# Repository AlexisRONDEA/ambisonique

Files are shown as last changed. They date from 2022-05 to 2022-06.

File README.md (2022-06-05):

#	  Projet : Ambisonique
  
Collaborateurs : RONDEAU Alexis, SOULE Zeïck, BODET Amaury, VAN DE MOOSDIJK Martina, MILLASSEAU Adrien, LATHUILLERE Colin

###	I / Introduction
	
Ce projet, initialement conçu par des troisièmes années, permet de connecter huit enceintes pour délivrer un son provenant de différentes directions.
Nos objectifs concernent l’encombrement et la qualité sonore de l’amplificateur audio. En effet, les enceintes sont pour l’instant alimentées par des alimentations de laboratoire, ce qui est peu pratique et prend de la place. De plus, le signal audio est transmis par un seul fil. Cette liaison asymétrique est la source de parasite sur le signal et donne lieu à une mauvaise qualité sonore. 
On se propose donc de remplacer la transmission du signal par une liaison symétrique différentielle, pour supprimer le plus de parasites possible. On change l’amplificateur actuel par un amplificateur de classe D pour améliorer la qualité sonore du signal en sortie. Enfin, on fait passer l’alimentation des enceintes par le câble transmettant le signal audio, pour alimenter les enceintes avec le réseau.
Pour cela on sépare ce projet en quatre modules et en deux PCB. Les deux premiers appartiendront au premier et le séparateur avec l’ampli audio seront sur le deuxième PCB.

Objectifs : 
- Créer un module modifiant le courant d'entrée du réseau 230V AC en 24V DC
- Créer un module qui additionne la partie continue de 24V au signal
- Créer un module qui sépare le signal et la puissance pour alimenter les enceintes
- Créer l’amplificateur de classe D
 
Le [cahier des charges](https://github.com/AlexisRONDEA/ambisonique/blob/main/livrables/Cahier%20des%20Charges%20-%20Ambisonique%20%5B2%5D.pdf), le [diagramme d’architecture](https://github.com/AlexisRONDEA/ambisonique/blob/main/livrables/Diagramme%20Architecture%20-%20Ambisonique%20%5B2%5D.pdf), la [présentation PDF](https://github.com/AlexisRONDEA/ambisonique/blob/main/livrables/Diagramme%20Architecture%20-%20Ambisonique%20%5B2%5D.pdf) du projet ainsi que les [commandes des composants](https://github.com/AlexisRONDEA/ambisonique/tree/main/livrables) se trouvent dans le dossier « [livrables](https://github.com/AlexisRONDEA/ambisonique/tree/main/livrables) ».

###	II / Alimentation du circuit

Pour ce module on utilise les composants suivants :
-	Un connecteur MPT 0.5/2-2.54
-	Un transformateur PCB, 230V, 2 * 24V
-	Un pont redresseur monophasé
-	Un contrôleur DC/DC, synchrone, Buck, output 24V

Le transformateur permet de modifier la tension d’entrée du réseau de 230V alternatif en 24V alternatif. Le courant est ensuite envoyé dans le pont de diode redresseur qui renvoie une tension de 33V continu en sortie. Enfin, le contrôleur Buck abaisse la tension à 24V continu pour l’envoyer dans le module additionneur.

Dans un premier temps, pour créer ce module on voulait utiliser un montage avec un régulateur de tension. Cependant, ce circuit était assez vieux et donc pas assez performant par rapport à d’autres montages envisageables. Les pertes étaient trop importantes et c’est pour cela que nous avons décidé d’opter pour ce circuit actuel. 
De plus, notre circuit actuel devait utiliser les deux branches de sortie du transformateur qui fournit du 2x24V, car une fois 24V n’aurait pas était suffisant. Cependant la tension de sortie correspond à un courant alternatif, qui est donc redresser par le pont de diode ensuite à 33V continu. C’est pourquoi on n’utilise qu’une seule branche de sortie du transformateur.  

 Ce module fait partie du premier PCB, les fichiers utiles au PCB sont donc [ambisoniqueAlim.sch](https://github.com/AlexisRONDEA/ambisonique/blob/main/PCB/SchematicAlim.png) et [ambisoniqueAlim.brd](https://github.com/AlexisRONDEA/ambisonique/blob/main/PCB/BoardAlim.png). Les empreintes du contrôleur Buck et du transformateur ont été créé pour Eagle tandis que l’empreinte du pont redresseur a été téléchargée sur internet. 

###	III / Additionneur

Pour ce module, on utilise les composants suivants : 

-	Deux transistors de puissance NPN TIP31A 
-	Deux connecteurs Jack 

On réalise un montage à collecteur commun en utilisant le TIP31A. Il permet d'obtenir en sortie, au niveau de l'émetteur et dans le même fil, le signal audio ainsi que les 24 V DC obtenus dans le module précédent. On assure la transmission par un seul câble XLR. On souhaite également avoir un courant de 1.5 A en sortie du transistor, d'où le choix d'un transistor de puissance pour réaliser ce montage. Enfin, on réalise ce montage deux fois, avec un signal audio positif puis négatif afin de pouvoir les soustraire et travailler en différentiel. L'objectif du différentiel est d'éviter les perturbations électromagnétiques, qui se répercutent sur les deux signaux. En les soustrayant, on efface alors les parasites. On souhaite également éviter d'impacter la valeur continue, en choisissant judicieusement la valeur des résistances. 

Nous avons pensé à réaliser ce module en utilisant un schéma additionneur avec un amplificateur opérationnel, néanmoins cela aurait été compliqué car il nous fallait avoir un courant conséquent en sortie, ce qui n'est pas possible avec un AOP. 

Ce module fait partie du premier PCB, les fichiers utiles au PCB sont donc [ambisoniqueAlim.sch](https://github.com/AlexisRONDEA/ambisonique/blob/main/PCB/SchematicAlim.png) et [ambisoniqueAlim.brd](https://github.com/AlexisRONDEA/ambisonique/blob/main/PCB/BoardAlim.png).

 ###	IV / Séparateur 
 
Pour ce module on utilise les composants suivants :
-	Deux contrôleurs DC/DC, synchrone, Buck, output 12V

Pour ce module, on utilise des condensateurs. On utilise leur caractéristique de filtre pour séparer la composante continue et le signal. On souhaite séparer la composante continue afin de l'utiliser en tant qu'alimentation pour les enceintes, et d'utiliser la composante alternative pour l'amplifier dans le module suivant. Les deux câbles de puissance rentrent alors dans les contrôleurs Buck qui renvoient une tension de 12V. On fait se rejoindre les deux câbles, puis on les sépare pour alimenter le microprocesseur et les MOSFET. En effet, les MOSFET sont directement alimentés en 12V, tandis que la tension d’entrée du microprocesseur passe par un régulateur avant d’alimenter le microprocesseur en 3,3V. 

Pour ce module, on a dû recommander les contrôleurs Buck. En effet, ceux commandés ne pouvait que donner du 5V en sortie contrairement aux 12V voulus.

Ce module fait partie du second PCB, les fichiers utiles au PCB sont donc [ambisoniqueAmpli.sch](https://github.com/AlexisRONDEA/ambisonique/blob/main/PCB/SchematicAmpli.png) et [ambisoniqueAmpli.brd](https://github.com/AlexisRONDEA/ambisonique/blob/main/PCB/BoardAmpli.png).

###	V / Amplificateur audio

Pour ce module on utilise les composants suivants :
-	Un microcontrôleur STM32L412KBT6
-	Un MOSFET de puissance, Canal N, 20 V, 3.9 A, 0.025 Ohm
-	Un MOSFET de puissance, Canal P, 20 V, 3.2 A, 0.08 Ohm

L’objectif de cette partie du projet est de remplacer l’amplificateur audio déjà existant en le substituant par un microprocesseur. Ce dernier permet de créer une PWM qui rentre ensuite dans un amplificateur de classe D composé des deux MOSFET de puissance. Pour ce faire, on alimente le microprocesseur avec du 3,3V venant du module séparateur et les MOSFET en 12V. Le microprocesseur récupère le signal différentiel en entrée et le traite, pour retourner un signal simple avec le moins de parasites possible. Ensuite, le signal est comparé à un signal triangle, modélisé par un compteur TIMER sur le microprocesseur, pour générer la PWM. 

Nous voulions d’abord utiliser d’autres circuits, avec d’autres types d’amplificateur. Cependant, cet amplificateur de classe D est le plus performant. 
De plus, la programmation du microprocesseur n’est pas terminée.

Ce module fait partie du second PCB, les fichiers utiles au PCB sont donc [ambisoniqueAmpli.sch](https://github.com/AlexisRONDEA/ambisonique/blob/main/PCB/SchematicAmpli.png) et [ambisoniqueAmpli.brd](https://github.com/AlexisRONDEA/ambisonique/blob/main/PCB/BoardAmpli.png). Les empreintes des MOSFET viennent d’internet, et celle du microprocesseur nous a été fournie en amont.

###	VI / Conclusion

Pour finir, voici les problèmes généraux que l'on a rencontrés ainsi que le résultat des tests effectués. Tout d'abord, nous n'avons pas testé les contrôleurs Buck séparément du reste du circuit. En effet, nous n'avons pas fait de PCB unitaire avant de passer au PCB complet. De plus, nous n'avons pas placé de points de test pour vérifier le bon fonctionnement de notre circuit. Finalement, nous aurions dû vérifier l'isolation nécessaire entre les pistes parcourue par le courant issu du réseau, pour être certain d'éviter le phénomène d'arc électrique. 

Lors des tests des PCB, on a remarqué que les Bucks ne fonctionnaient pas, sûrement à cause d'une mauvaise soudure. Quant à l'autre PCB, il y a échauffement des composants et la tension de sortie est de 15V au lieu de 24V comme attendu. Il faudrait aussi tester le code du microprocesseur, et voir si ce dernier s'allume correctement avec le reste du circuit.

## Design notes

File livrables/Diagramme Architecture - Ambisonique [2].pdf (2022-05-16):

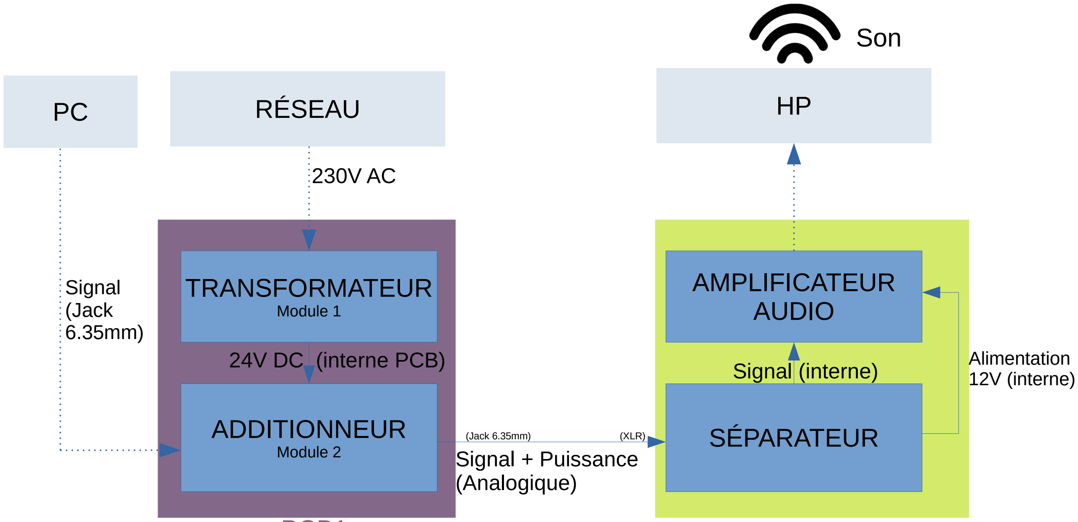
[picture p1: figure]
TRANSFORMATEUR; Module 1; ADDITIONNEUR; Module 2; Signal (Jack 6.35mm); Signal + Puissance (Analogique); (interne PCB); SÉPARATEUR; AMPLIFICATEUR AUDIO; Signal (interne); Alimentation; 12V (interne); RÉSEAU; Son; (Jack 6.35mm); (XLR)

PCB1 | PCB2

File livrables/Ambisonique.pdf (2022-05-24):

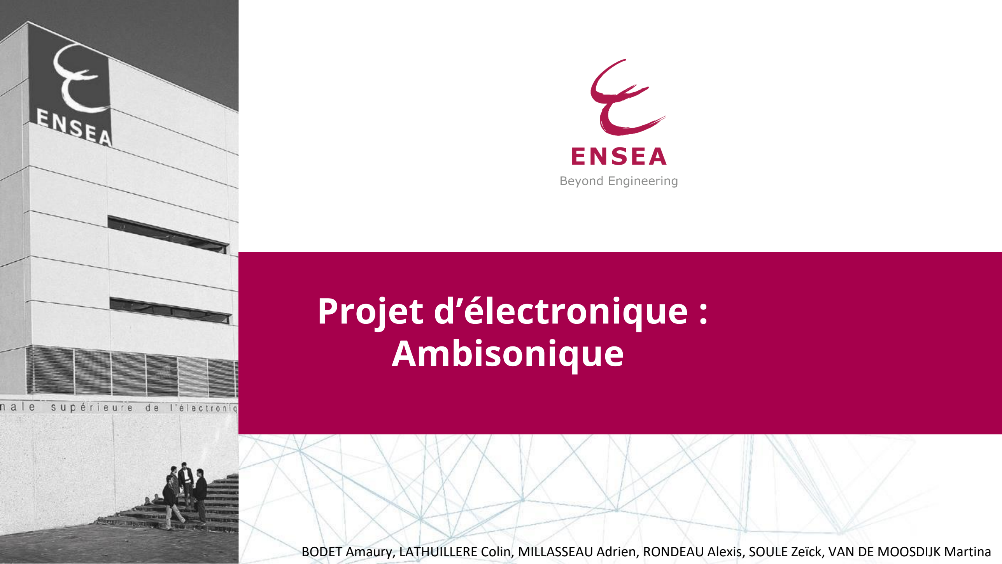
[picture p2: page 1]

## Projet d’électronique : Ambisonique

BODET Amaury, LATHUILLERE Colin, MILLASSEAU Adrien, RONDEAU Alexis, SOULE Zeïck, VAN DE MOOSDIJK Martina

## Sommaire

Mai 2022 – 2 / 21

1

2

4

3

Présentation générale du projet

Module Alimentation 230V AC – 12V DC

Module Ampli audio 15 W sous 8Ω

Module Signal audio symétrique + puissance en câble XLR

5 Conclusion

## Présentation générale du projet

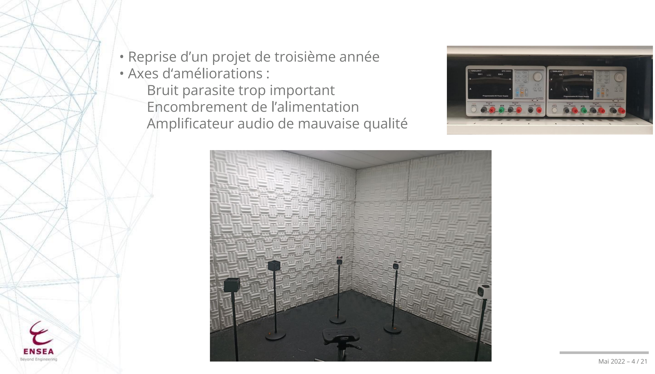
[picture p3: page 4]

- Reprise d’un projet de troisième année
- Axes d‘améliorations :
Bruit parasite trop important Encombrement de l’alimentation Amplificateur audio de mauvaise qualité

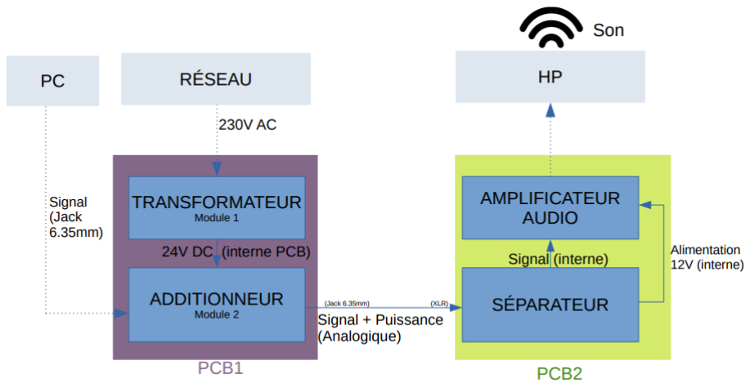
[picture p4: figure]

## Module Alimentation 230V AC – 12V DC

Contraintes:
- Norme IP40D
- Dimensions finales égales à celle d’un rack audio

Objectifs:
- Transformation du courant 230V AC vers 24V DC
- Branchement au secteur

### Introduction

### Schéma du module

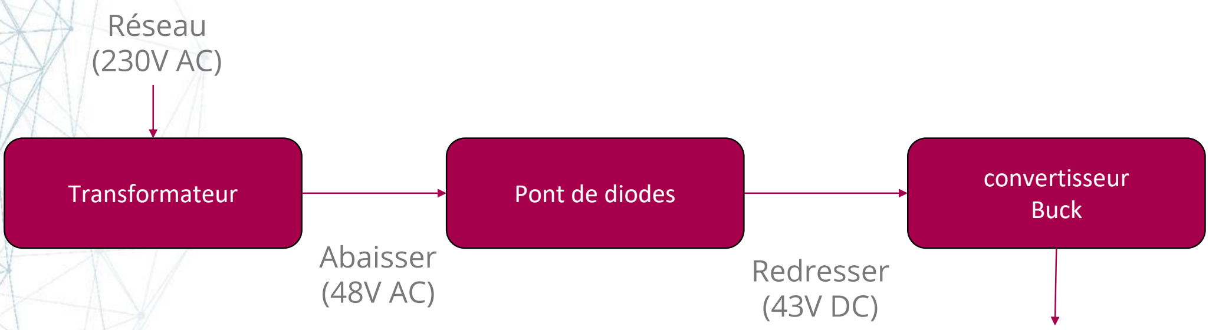
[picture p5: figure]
Transformateur; Pont de diodes; convertisseur; Buck; Réseau (230V AC); Abaisser; Redresser

Additionneur
(24V DC)

### PCB

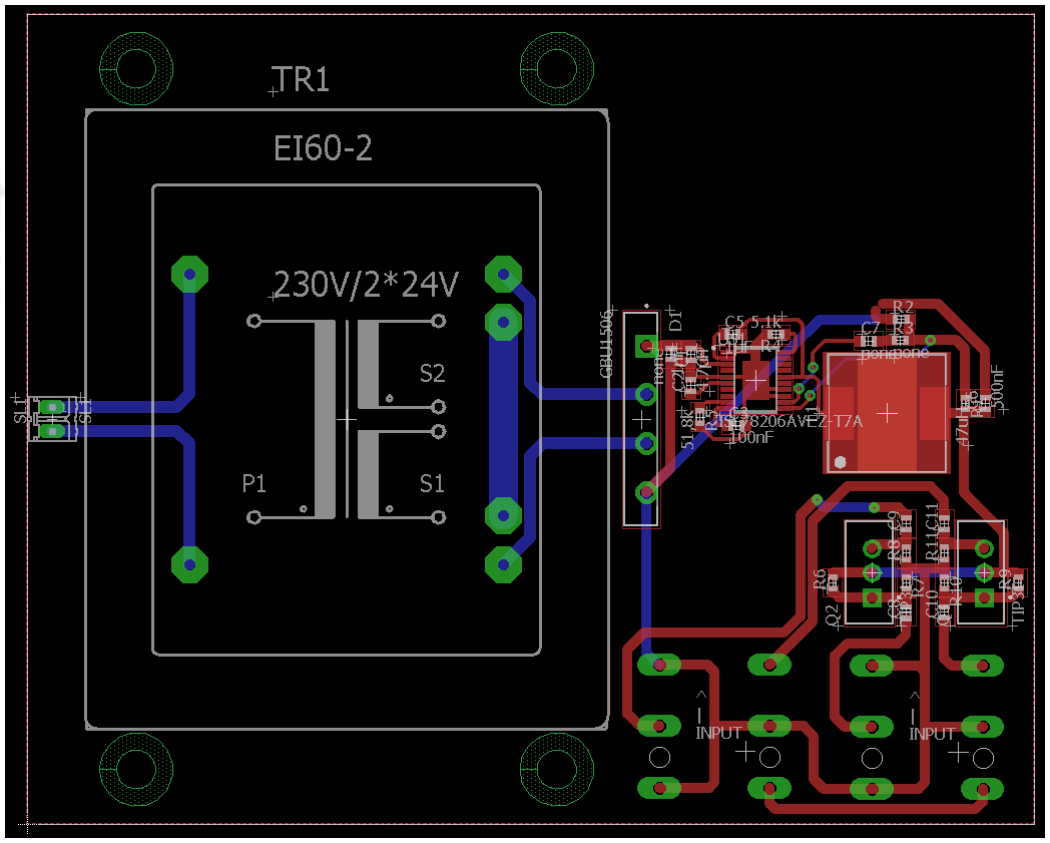
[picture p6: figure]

## Module Signal audio symétrique + puissance en câble XLR

Contraintes:
- Utilisation d’un seul câble de transmission
- Transmission d’un signal différentiel

Objectifs:
- Addition du signal à la puissance
- Transmission du signal sans parasites
- Séparation du signal et du continue

### Introduction

### Schéma du module

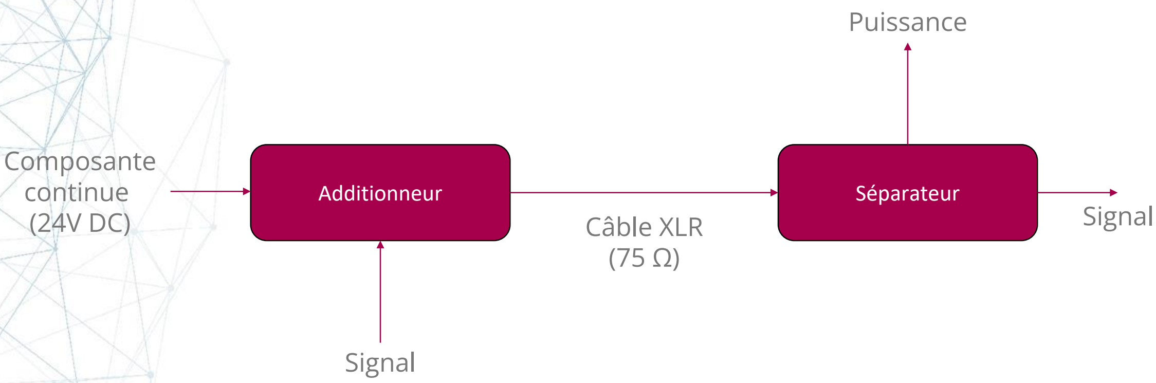
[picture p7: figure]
Additionneur; Séparateur; Composante continue (24V DC); Signal; Puissance; Câble XLR (75 Ω)

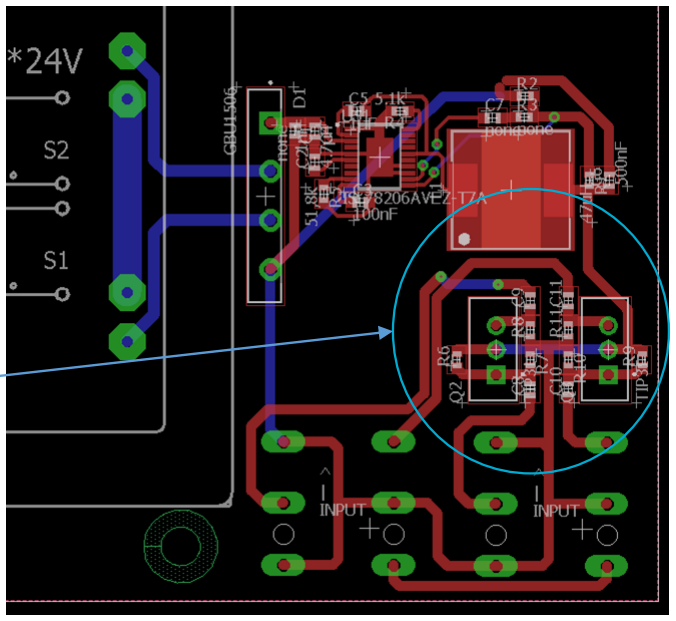
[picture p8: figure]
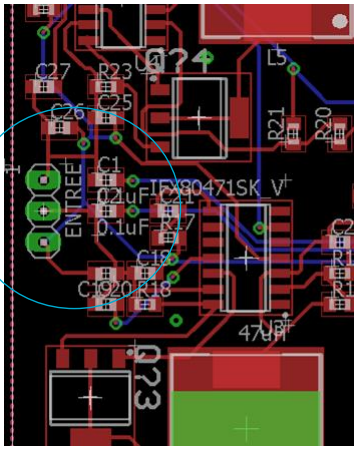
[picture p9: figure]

Additionneur
Séparateur

### PCB

## Module Ampli audio 15 W sous

8Ω

Contraintes:
- Utilisation du microprocesseur
- Amplification du signal de 15W sous 8Ω

Objectifs:
- Amplification du signal
- Transformation du signal différentiel
- Régulation de la puissance d’alimentation

### Introduction

Schéma du | PCB

### module

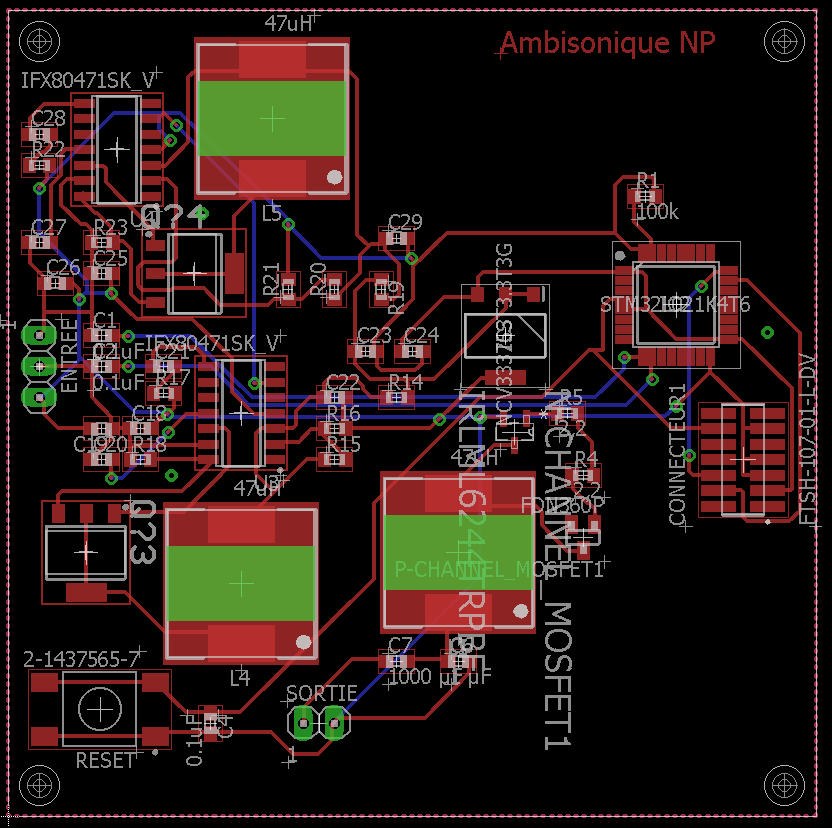
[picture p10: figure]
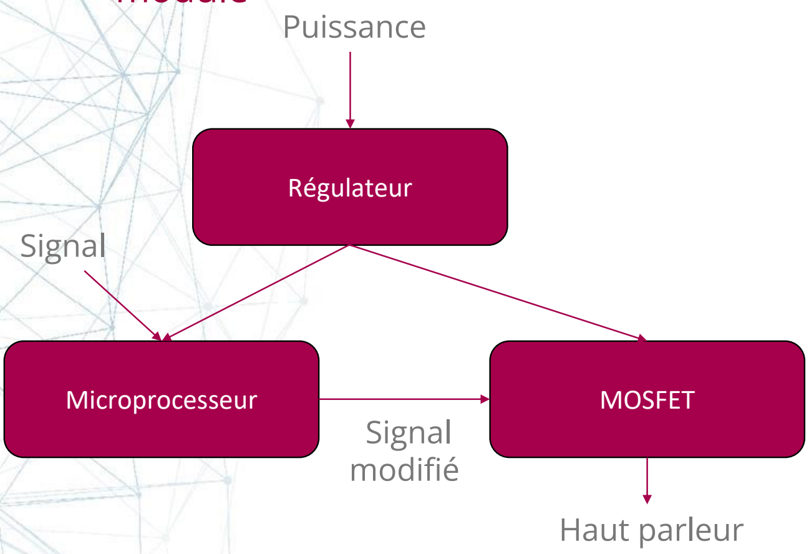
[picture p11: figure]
Régulateur; Microprocesseur; MOSFET; Puissance; Signal; Haut parleur; Signal modifié

### Programmation du microprocesseur

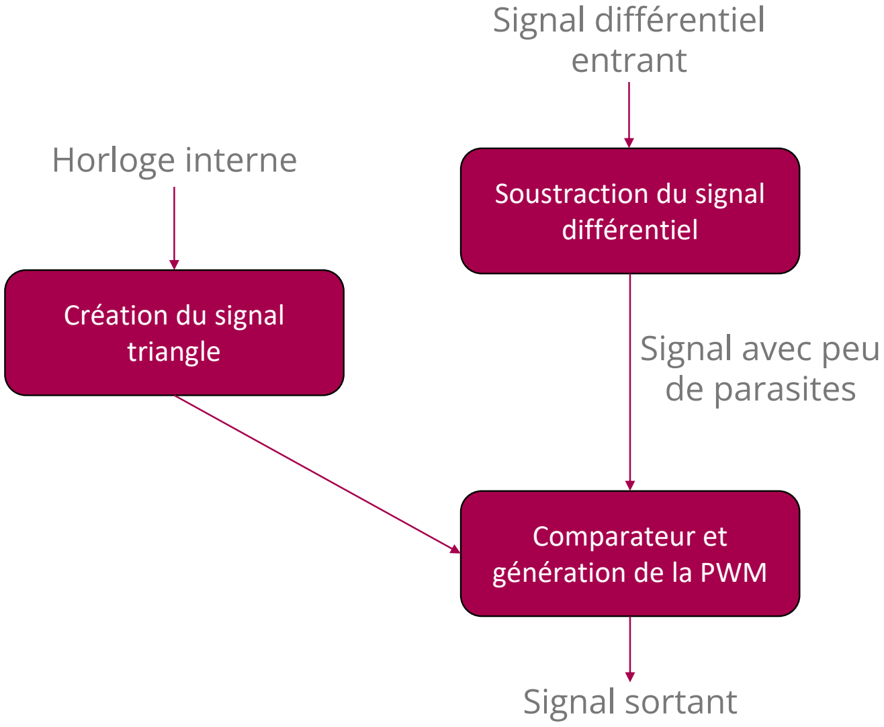
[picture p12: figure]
Création du signal triangle; Soustraction du signal différentiel; Comparateur et génération de la PWM; Signal sortant; Horloge interne; Signal différentiel entrant; Signal avec peu de parasites

## Conclusion

Objectifs à atteindre :
- Finir le PCB
- Terminer le code du microprocesseur
- Tester les modules

### Conclusion

Axes de développement :
- Création d’un boîtier plastique pour le module de transformation du courant
- Multiplication du projet pour les huit enceintes initiales
- Interface homme-machine pour mettre hors tension

### Conclusion

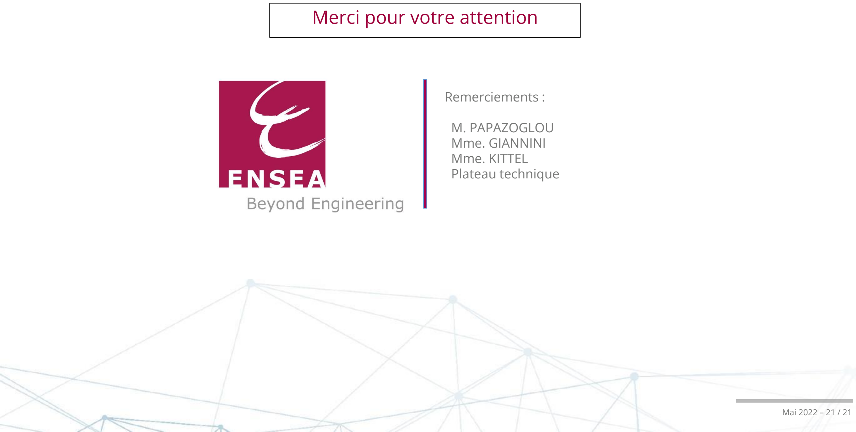
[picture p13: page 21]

Remerciements :

M. PAPAZOGLOU
Mme. GIANNINI
Mme. KITTEL
Plateau technique

Merci pour votre attention

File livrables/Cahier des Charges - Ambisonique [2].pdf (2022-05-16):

Adrien MILLASSEAU - Colin LATHUILLERE - Zeïck SOULE - Alexis RONDEAU - Amaury BODET – Martina VAN DE MOOSDIJK

# CAHIER DES CHARGES

Système ambisonique

OBJECTIF :
Amélioration hardware d’un projet de 3eme année SIA (Système de spatialisation sonore ambisonique).
1) Module 1 : Transformateur
- Transformation du courant
- Entrée : 230V AC (Réseau)
- Sortie : 12V DC
- Norme IP
➢IP 40D
(Protection de la personne contre l’accès aux parties dangereuses avec un fil)
- Réduction de l’encombrement
- Dimensions visées : 42 x 33 x 4.5 cm
- Commun Module 1 et 2
2) Module 2 : Additionneur 12 DC avec signal
- Passage de l’alimentation et du signal dans un seul câble ➢Entrée : Signal (Jack 6.35mm)
➢Sortie : Puissance (1.5A / HP) + Signal (Jack 6.35mm)
- Analogiquement
3) Module 3 : Ampli audio, séparation puissance et signal
- Entrée : 12V + signal (provenant de l’additionneur)
- Séparation puissance/signal analogique
- Echantillonage du signal par Codec
- Filtrage numérique par microprocesseur
- Amplification du signal (ampli 15W pour une charge de 8Ω)

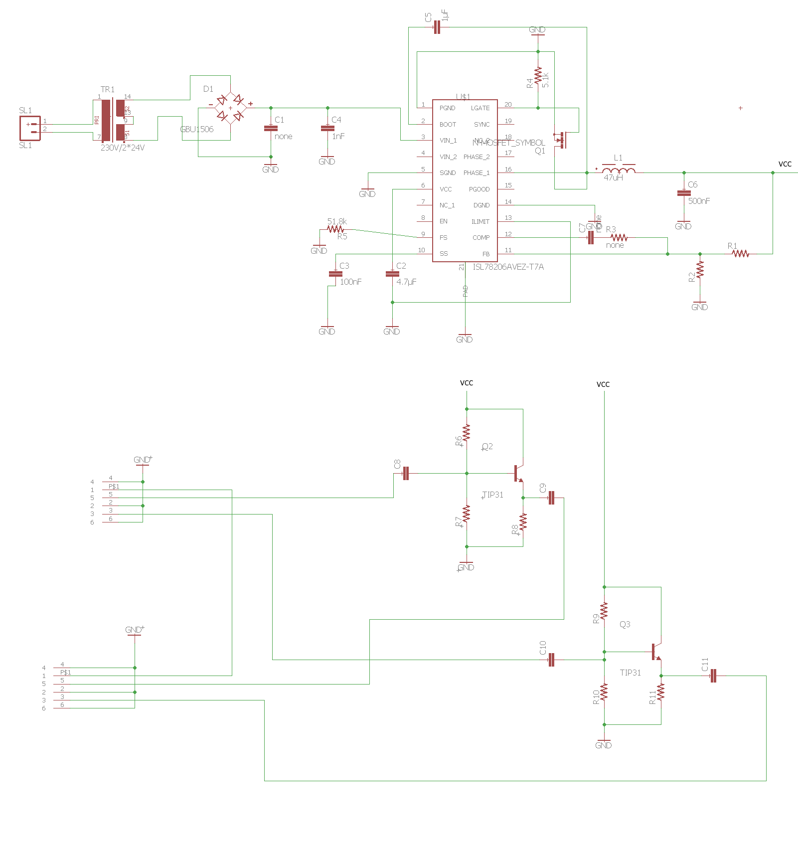
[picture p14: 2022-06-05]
PCB/SchematicAlim.png

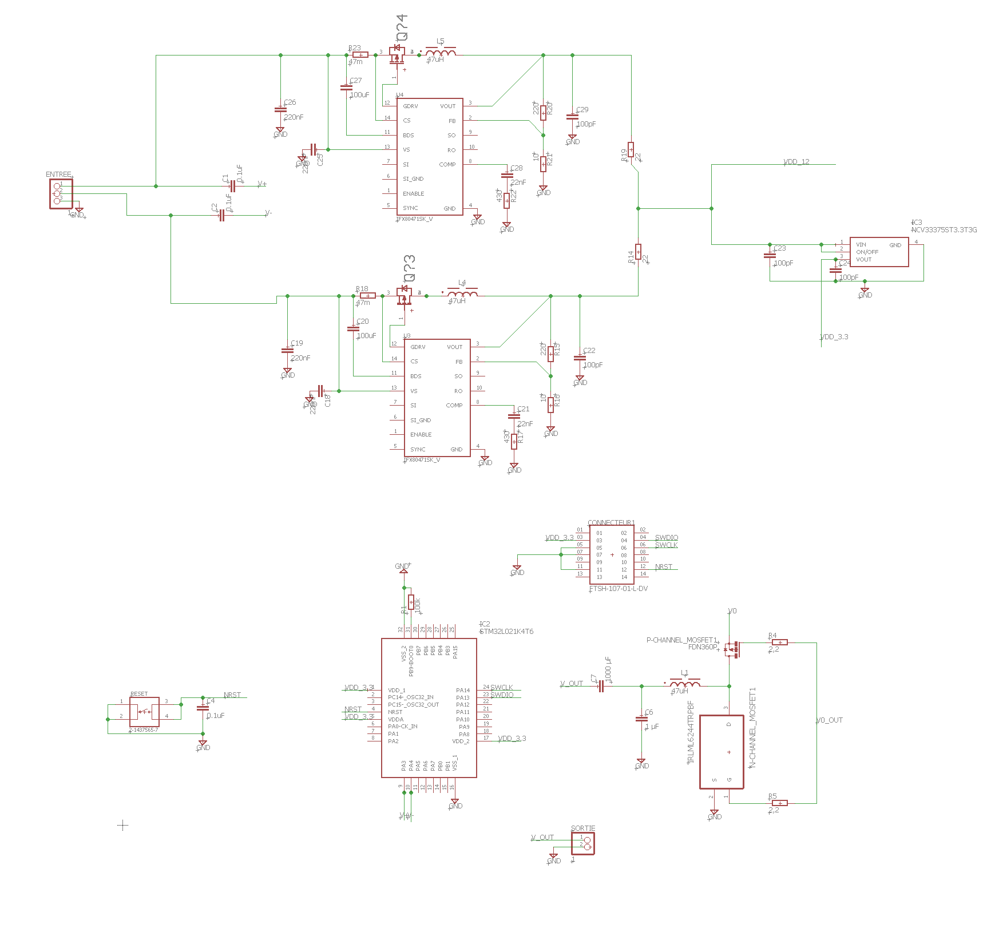
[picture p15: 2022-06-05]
PCB/SchematicAmpli.png

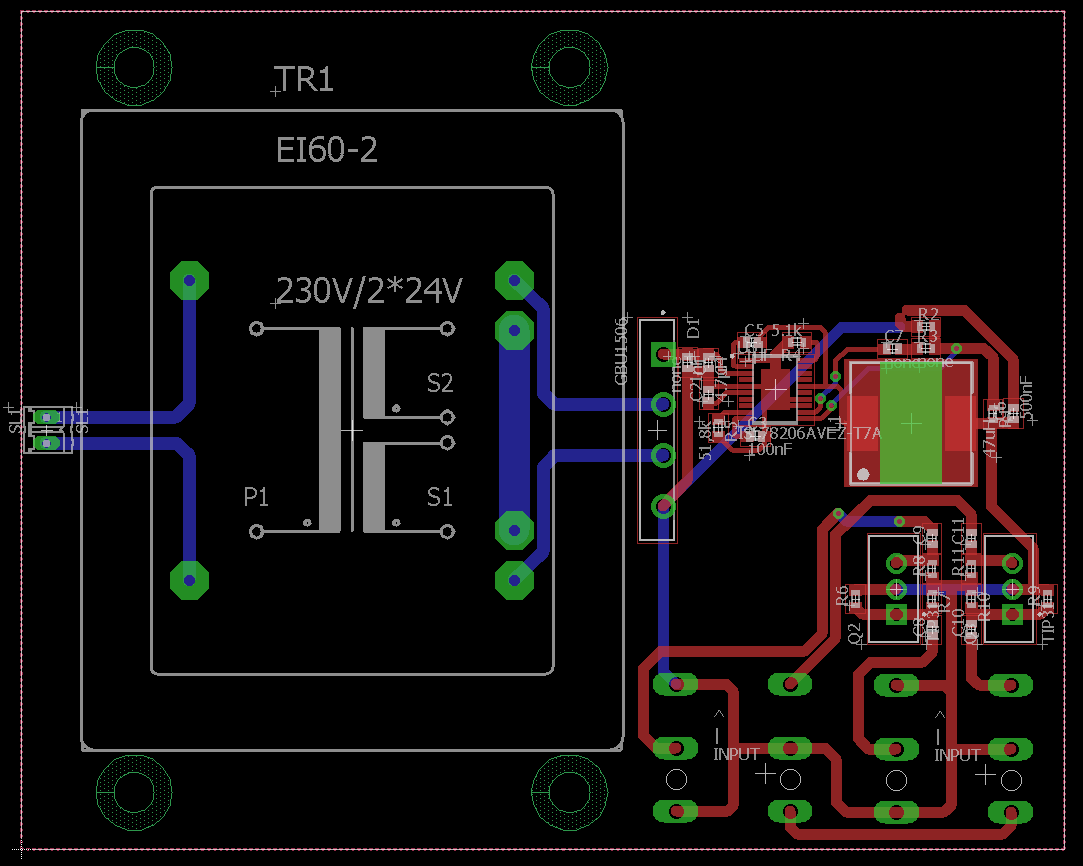
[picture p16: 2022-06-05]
PCB/BoardAlim.png

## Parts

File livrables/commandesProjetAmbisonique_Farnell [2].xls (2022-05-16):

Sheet: 1 commande par mail
Farnell |  |  |  |  | Envoyez un seul fichier par mail!
Pos | I | P | Art | Désignation | Qté commandée | UA | Date Livraison | Prix unitaire | Devise | Q | Grpe | Div
10 | Z |  |  | 2780880 Controleur DC/DC Output 12V | 1 | PC | 17.05.2022 | 2.43 | EUR | PC | TA.01
20 | Z |  |  | 9294333 Transistor TIP31A | 2 | PC | 17.05.2022 | 1.55 | EUR | PC | TA.01
30 | Z |  |  | 2543346 Controleur DC/DC Output 24V | 1 | PC | 17.05.2022 | 6.98 | EUR | PC | TA.01
40 | Z |  |  |  |  | PC |  |  | EUR | PC | TA.01
50 | Z |  |  |  |  | PC |  |  | EUR | PC | TA.01
60 | Z |  |  |  |  | PC |  |  | EUR | PC | TA.01
70 | Z |  |  |  |  | PC |  |  | EUR | PC | TA.01
80 | Z |  |  |  |  | PC |  |  | EUR | PC | TA.01
90 | Z |  |  |  |  | PC |  |  | EUR | PC | TA.01
100 | Z |  |  |  |  | PC |  |  | EUR | PC | TA.01
110 | Z |  |  |  |  | PC |  |  | EUR | PC | TA.01
120 | Z |  |  |  |  | PC |  |  | EUR | PC | TA.01
130 | Z |  |  |  |  | PC |  |  | EUR | PC | TA.01
140 | Z |  |  |  |  | PC |  |  | EUR | PC | TA.01
150 | Z |  |  |  |  | PC |  |  | EUR | PC | TA.01
160 | Z |  |  |  |  | PC |  |  | EUR | PC | TA.01
170 | Z |  |  |  |  | PC |  |  | EUR | PC | TA.01
180 | Z |  |  |  |  | PC |  |  | EUR | PC | TA.01
190 | Z |  |  |  |  | PC |  |  | EUR | PC | TA.01
MODE d'EMPLOI et CODE erreurs Version 19
1: indiquez le fournisseur ligne 1
2:remplissez pour chaque ligne commandée les 4 champs en rouge selon les règles suivantes:
 | Art
 |  |  | 2.1 | Ne mettez rien ici tout comme dans P: remplissez les zones rouges (et pas ailleurs)
 | Désignation
 |  |  | 2.2 | Ne dépassez pas les 40 caractères: il seront automatiquement effacés lors de la recopie
 |  |  | 2.3 | Mettre le code commande impérativement en premier suivi d'une courte description
 |  |  | 2.4 | Pour RS et Farnell : mettre le code commande RS ou Farnell (7 à 9 chiffres) (et pas la référence constructeur) suivie d'une courte description
 |  |  | 2.5 | Exemple: 125-4857 capa 1uF 0508
 | Qté commandée
 |  |  | 2.6 | C'est le nombre d'unités correspondant au prix unitaire
 |  |  | 2.7 | Attention il y a des pièges
 |  |  | 2.8 | avec RS par exemple on vous demande parfois de commander par lot de 5 par exemple
 |  |  | 2.9 | si vous commandez 1 lot : le nombre d'unité est alors 5 pour 1 lot et non 1
 | date
 |  |  | 2.10 | Pour la date: mettre la date de dans une semaine
 |  |  | 2.11 | La mettre au format JJ.MM.AAAA
 |  |  | 2.13 | Bien utiliser les points comme séparateur
 | prix unitaire
 |  |  | 2.14 | Le prix est le prix HT (sans la TVA 20%) en euros d'une unité | sauf pour les commandes au comptant ou chez un fournisseur étranger (EXP-TECH par exemple): mettez le prix TTC
 |  |  | 2.15 | arrondi au centime supérieur (0.012 euros devient 0.02!)
 |  |  | 2.16 | avec pour séparateur le point
 |  |  | 2.17 | n'utilisez pas le symbole euros d'excel
3: frais de port
 |  |  | 3.1 | ajoutez une ligne pour les frais de port
 |  |  | 3.2 | dont la désignation est "frais de port"
 |  |  | 3.3 | pas de frais de port à mettre pour RS ou Farnell
 |  |  | 3.4 | Renseignez vous pour connaître les frais de port | 9,9 euros TTC chez EXP par exemple
4: conseils complémentaires
 |  |  | 4.1 | Ne modifier que les 4 champs en rouge
 |  |  | 4.2 | Ne pas modifier le document sinon cela n'a plus aucun intérêt
 |  |  | 4.3 | Mettez les références dans le même ordre que celui de la commande
 |  |  | 4.4 | Vérifier bien sur les sites les références et les prix!
 |  |  | 4.5 | N'oubliez pas les frais de port!: ajoutez une ligne pour les mentionner
5: sauvegardez le fichier au format xls

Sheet: Feuil1
Rapport sur la compatibilité concernant commandesProjet_v19.xls
Exécuté le 29/09/2020 17:26
Les fonctionnalités répertoriées ne seront pas disponibles si vous ouvrez le classeur dans une version antérieure d’Microsoft Excel ou si vous l’enregistrez dans un format de fichier antérieur.
Perte mineure de fidélité | Nb d'occurrences | Version
Certaines cellules ou certains styles de ce classeur contiennent une mise en forme qui n'est pas prise en charge par le format de fichier sélectionné. Ces formats seront convertis au format le plus proche disponible. | 1 | Excel 97-2003

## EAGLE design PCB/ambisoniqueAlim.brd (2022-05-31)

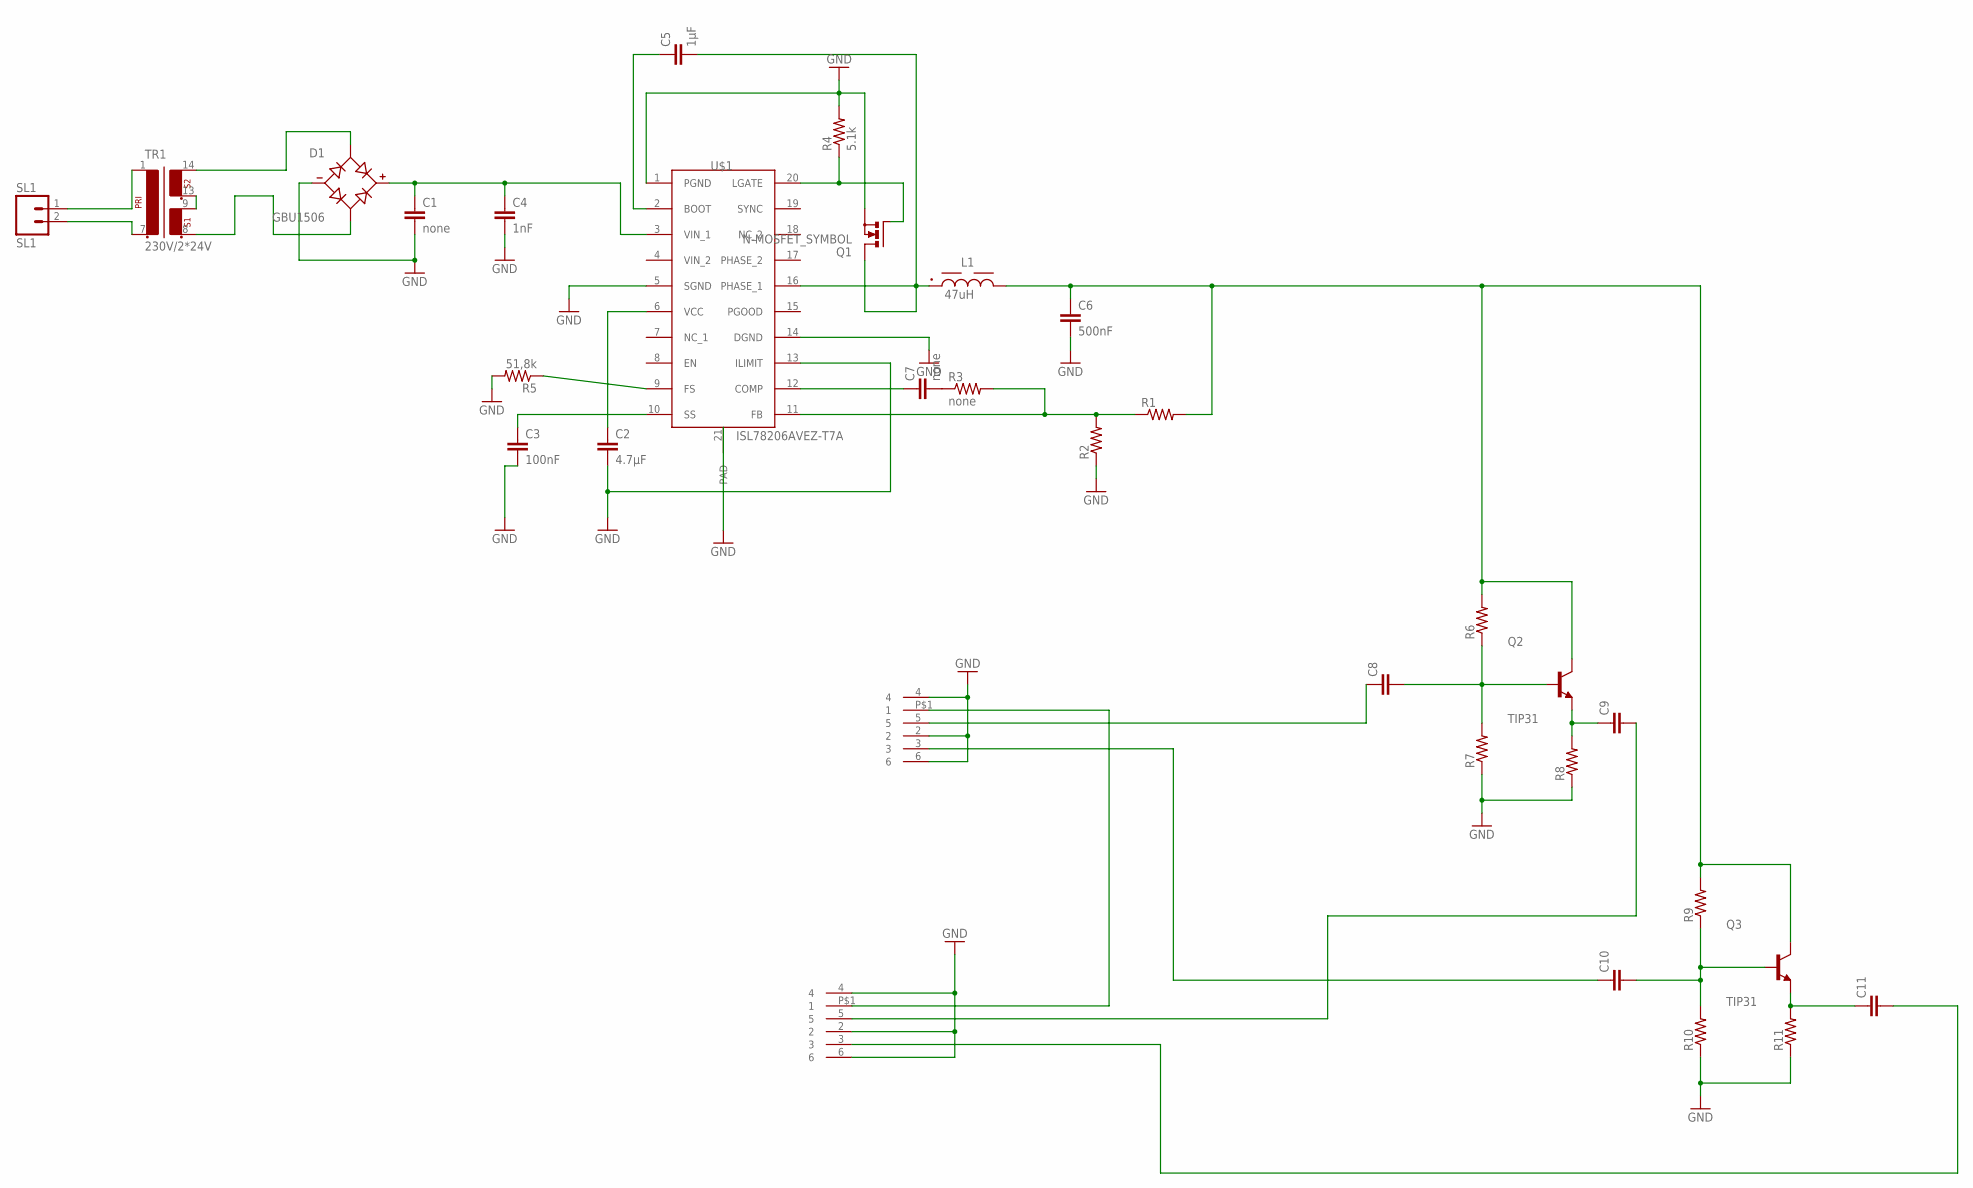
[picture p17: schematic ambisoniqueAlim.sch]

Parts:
C1, C7: none; C0603
C2: 4.7µF; C0603
C3: 100nF; C0603
C4: 1nF; C0603
C5: 1µF; C0603
C6: 500nF; C0603
C8, C9, C10, C11: C-EUC0603; C0603
D1: GBU1506; SIP343W114P508L2205H2134Q4
L1: 47uH; WE-PDA_1210
Q2, Q3: TIP31; TO254P1060X482X2222-3
R1, R2, R6, R7, R8, R9, R10, R11: R-US_R0603; R0603
R3: none; R0603
R4: 5.1k; R0603
R5: 51,8k; R0603
SL1: SL1; 02P
TR1: 230V/2*24V; EI60-2
U$1: ISL78206AVEZ-T7A; SOP65P640X110-21N
U$2, U$3: JACK6.35MMRSPRODEV; JACKRSPRO6.35MM

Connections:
GND: C1.2, C2.2, C3.2, C4.2, C6.2, D1.-, R2.1, R4.2, R5.2, R7.1, R8.1, R10.1, R11.1, U$1.1 (PGND), U$1.5 (SGND), U$1.13 (ILIMIT), U$1.14 (DGND), U$1.21 (PAD), U$2.2, U$2.4, U$2.6, U$3.2, U$3.4, U$3.6
unnamed: TR1.9 (4), TR1.13 (5)
unnamed: D1.AC1, TR1.14 (6)
unnamed: C2.1, U$1.6 (VCC)
unnamed: SL1.1, TR1.1
unnamed: SL1.2, TR1.7 (2)
unnamed: D1.AC2, TR1.8 (3)
unnamed: U$2.P$1 (1), U$3.P$1 (1)
unnamed: C1.1, C4.1, D1.+, U$1.3 (VIN_1)
unnamed: C3.1, U$1.10 (SS)
unnamed: C5.1, U$1.2 (BOOT)
unnamed: C10.2, Q3.1 (B), R9.1, R10.2
unnamed: C9.1, Q2.3 (E), R8.2
unnamed: R1.1, R2.2, R3.2, U$1.11 (FB)
unnamed: C7.1, U$1.12 (COMP)
unnamed: C7.2, R3.1
unnamed: R5.1, U$1.9 (FS)
unnamed: R4.1, U$1.20 (LGATE)
unnamed: C8.2, Q2.1 (B), R6.1, R7.2
unnamed: C9.2, U$3.5
unnamed: C11.1, Q3.3 (E), R11.2
unnamed: C6.1, L1.2, Q2.2 (C), Q3.2 (C), R1.2, R6.2, R9.2
unnamed: C5.2, L1.1, U$1.16 (PHASE_1)
unnamed: C11.2, U$3.3
unnamed: C10.1, U$2.3
unnamed: C8.1, U$2.5

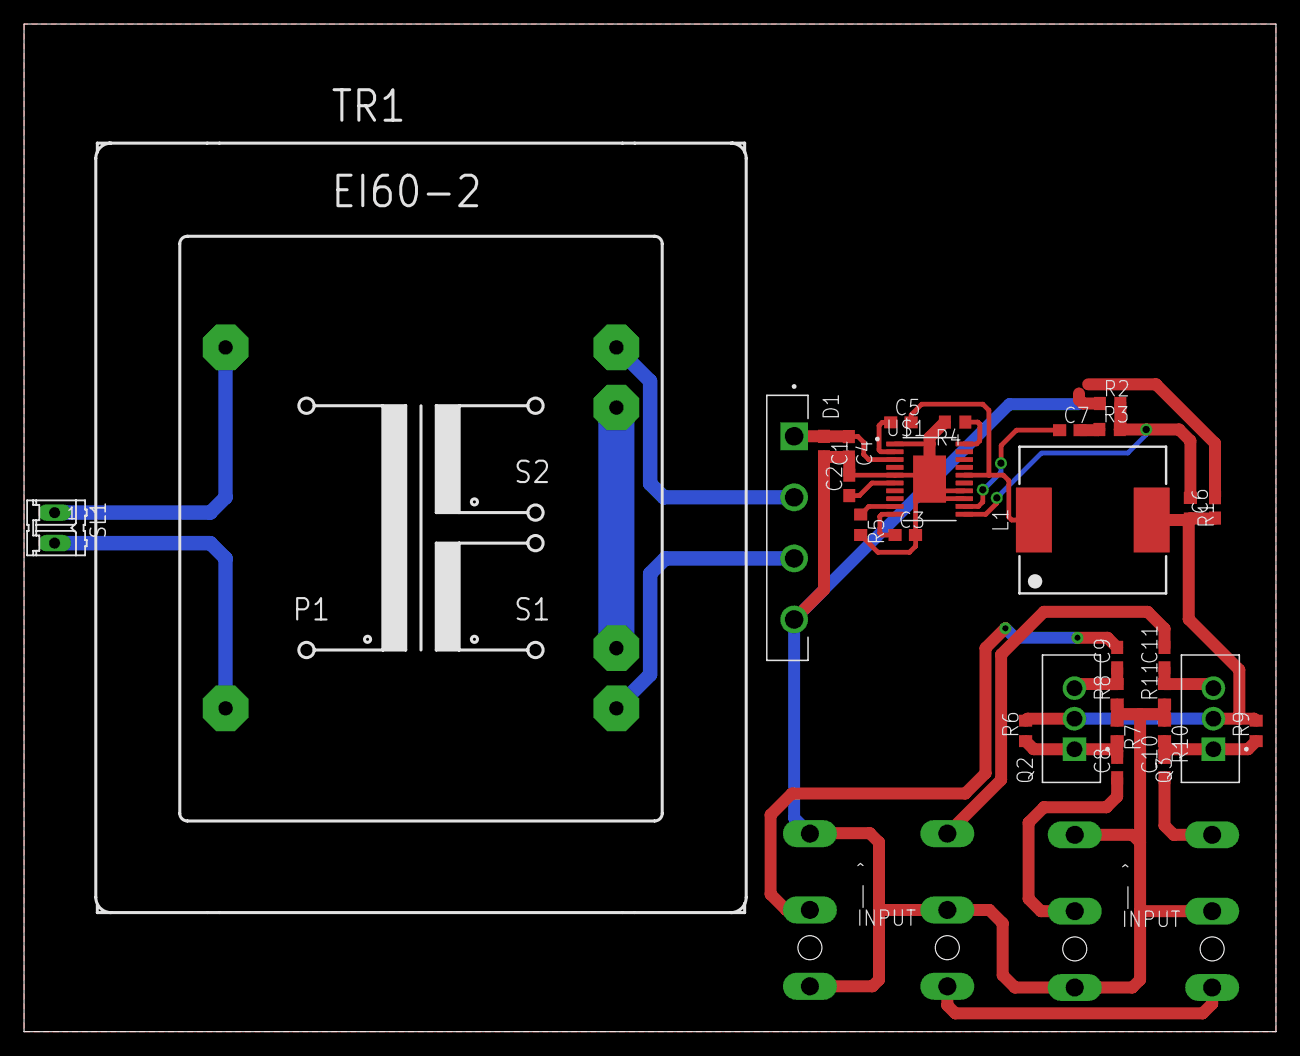
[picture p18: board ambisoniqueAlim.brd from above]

Board: 2 copper layers, 104.1 x 83.8 mm, 31 parts (0 on the bottom side), 26 nets.

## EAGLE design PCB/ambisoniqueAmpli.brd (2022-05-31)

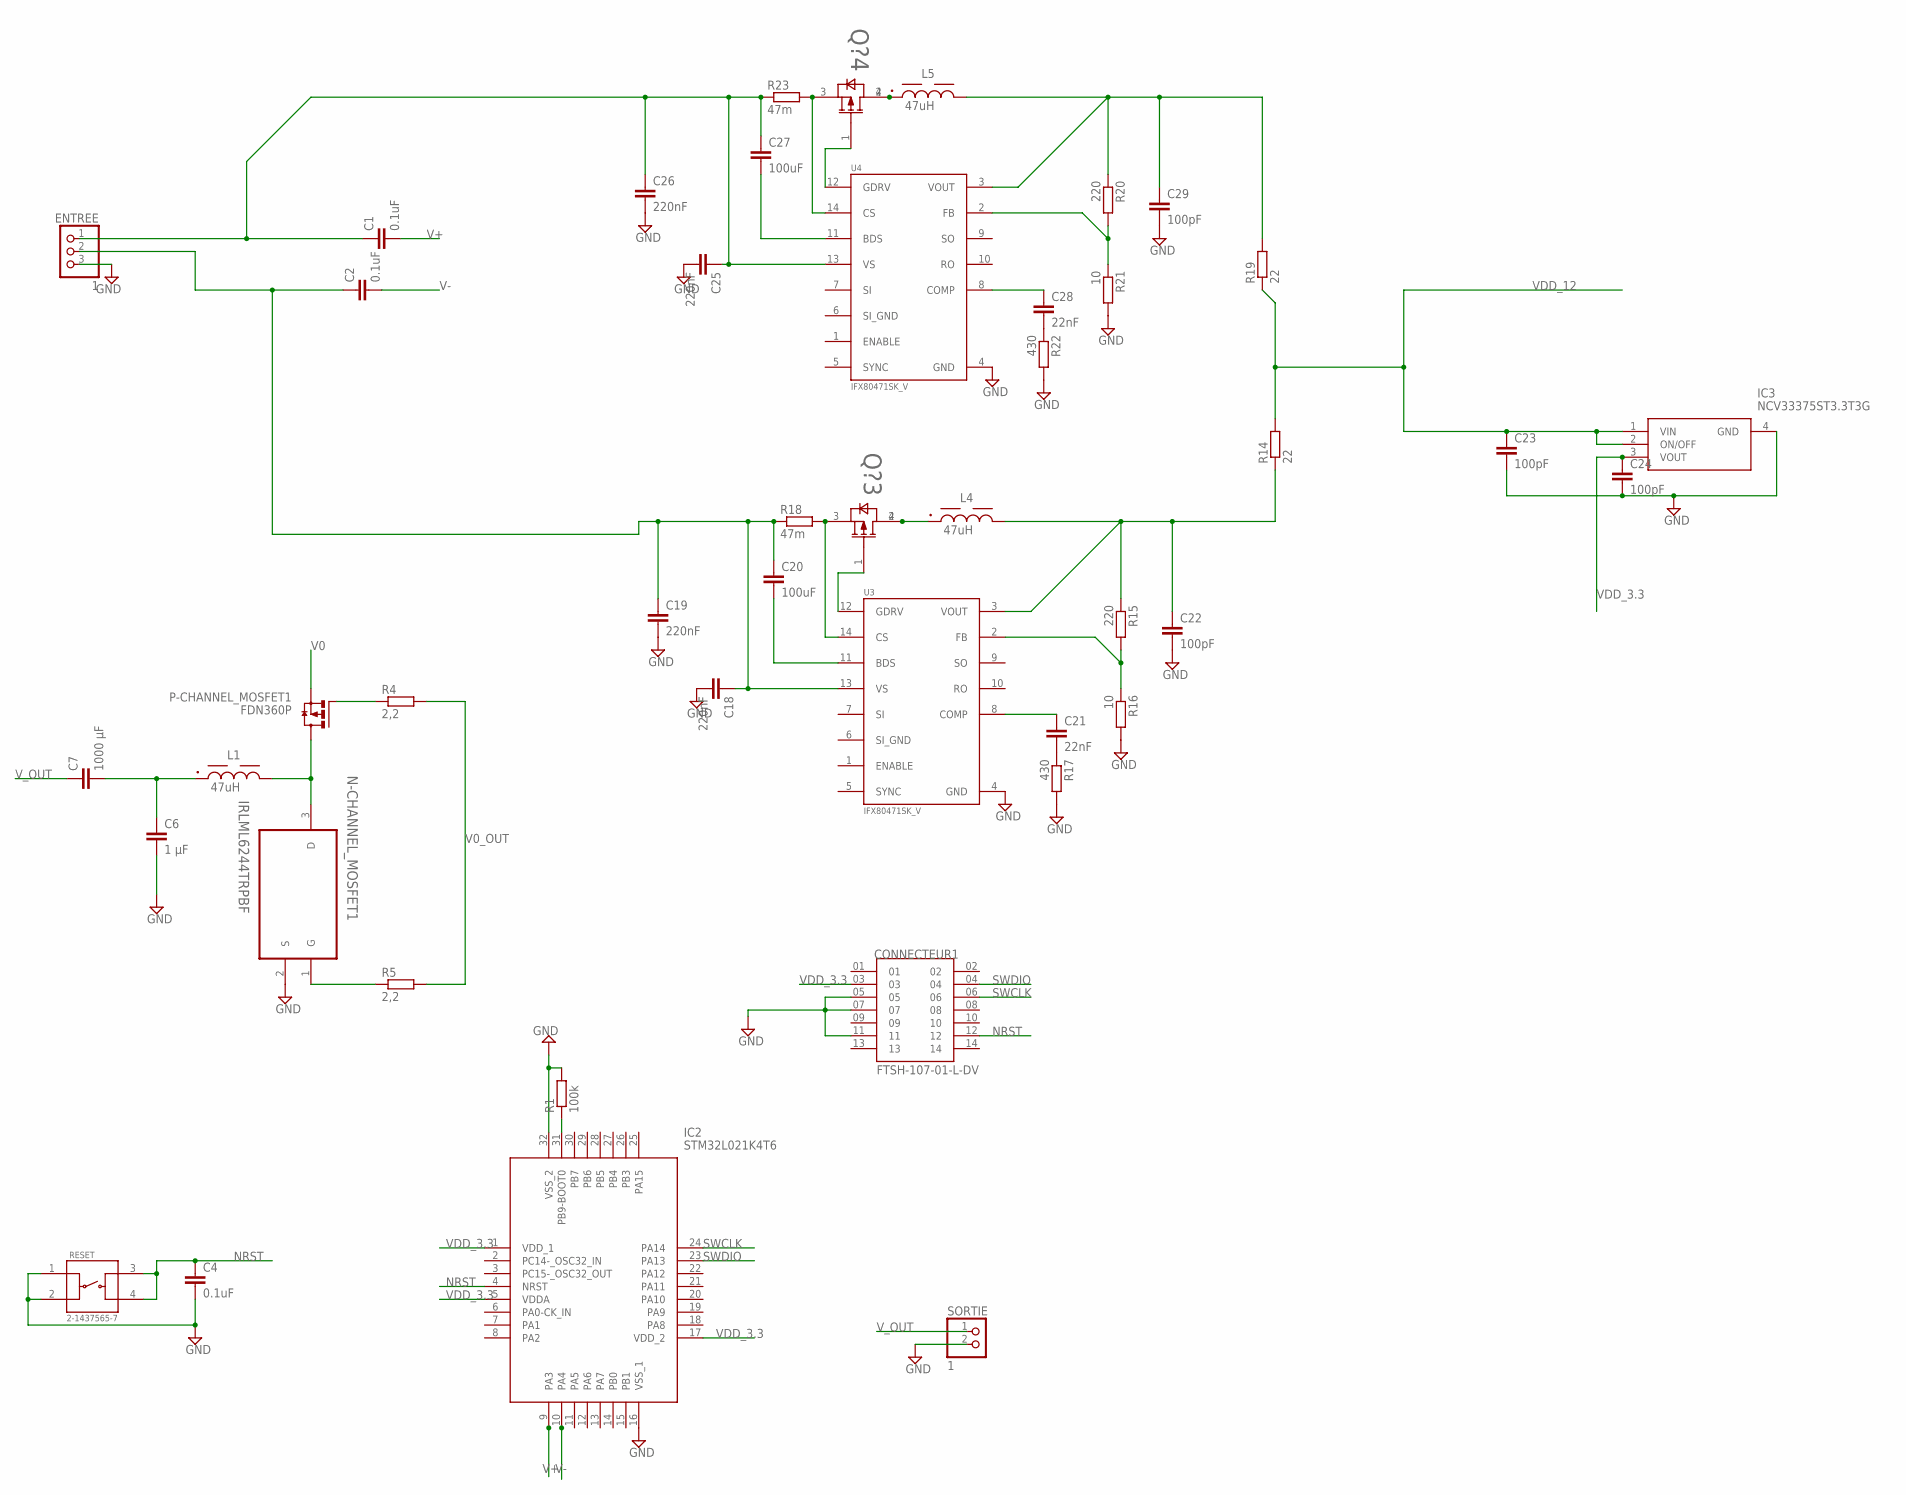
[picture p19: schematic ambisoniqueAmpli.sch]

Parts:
C1, C2, C4: 0.1uF; C0603
C6: 1 µF; C0603
C7: 1000 µF; C0603
C18, C19, C25, C26: 220nF; C0603
C20, C27: 100uF; C0603
C21, C28: 22nF; C0603
C22, C23, C24, C29: 100pF; C0603
CONNECTEUR1: FTSH-107-01-L-DV; SAMTEC_FTSH-107-01-L-DV
ENTREE: 1; 1X03
IC2: STM32L021K4T6; QFP80P900X900X160-32N
IC3: NCV33375ST3.3T3G; SOT230P700X175-4N
L1, L4, L5: 47uH; WE-PDA_1210
N-CHANNEL_MOSFET1: IRLML6244TRPBF; SOT95P237X112-3N
P-CHANNEL_MOSFET1: FDN360P; SUPER-SOT3
Q?3, Q?4: BSP613P; SOT230P700X170-4N
R1: 100k; R0603
R4, R5: 2,2; R0603
R14, R19: 22; R0603
R15, R20: 220; R0603
R16, R21: 10; R0603
R17, R22: 430; R0603
R18, R23: 47m; R0603
RESET: 2-1437565-7; SW_2-1437565-7
SORTIE: 1; 1X02
U3, U4: IFX80471SK_V; SOIC127P600X175-14N-8

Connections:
GND: C4.2, C6.2, C18.2, C19.2, C22.2, C23.2, C24.2, C25.2, C26.2, C29.2, CONNECTEUR1.05, CONNECTEUR1.07, CONNECTEUR1.11, ENTREE.3, IC2.16 (VSS_1), IC2.32 (VSS_2), IC3.4 (GND), N-CHANNEL_MOSFET1.2 (S), R1.2, R16.2, R17.2, R21.2, R22.2, RESET.1, RESET.2, SORTIE.2, U3.4 (GND), U4.4 (GND)
unnamed: C28.2, R22.1
unnamed: IC2.31 (PB9-BOOT0), R1.1
unnamed: C21.2, R17.1
unnamed: P-CHANNEL_MOSFET1.1 (G), R4.1
unnamed: L1.2, N-CHANNEL_MOSFET1.3 (D), P-CHANNEL_MOSFET1.3 (D)
unnamed: C6.1, C7.2, L1.1
unnamed: N-CHANNEL_MOSFET1.1 (G), R5.1
unnamed: Q?3.3 (SOURCE), R18.2, U3.14 (CS)
unnamed: Q?3.1 (GATE), U3.12 (GDRV)
unnamed: C20.2, U3.11 (BDS)
unnamed: L4.1, Q?3.2 (DRAIN_1), Q?3.4 (DRAIN_2)
unnamed: C21.1, U3.8 (COMP)
unnamed: R15.2, R16.1, U3.2 (FB)
unnamed: C22.1, L4.2, R14.1, R15.1, U3.3 (VOUT)
unnamed: Q?4.3 (SOURCE), R23.2, U4.14 (CS)
unnamed: Q?4.1 (GATE), U4.12 (GDRV)
unnamed: C27.2, U4.11 (BDS)
unnamed: L5.1, Q?4.2 (DRAIN_1), Q?4.4 (DRAIN_2)
unnamed: C28.1, U4.8 (COMP)
unnamed: R20.2, R21.1, U4.2 (FB)
unnamed: C29.1, L5.2, R19.2, R20.1, U4.3 (VOUT)
NRST: C4.1, CONNECTEUR1.12, IC2.4 (NRST), RESET.3, RESET.4
SI_GND: U3.6 (SI_GND), U4.6 (SI_GND)
SWCLK: CONNECTEUR1.06, IC2.24 (PA14)
SWDIO: CONNECTEUR1.04, IC2.23 (PA13)
V0: P-CHANNEL_MOSFET1.2 (S)
V0_OUT: R4.2, R5.2
V+: C1.2, IC2.9 (PA3)
V+_IN: C1.1, C25.1, C26.1, C27.1, ENTREE.1, R23.1, U4.13 (VS)
V-: C2.2, IC2.10 (PA4)
V-_IN: C2.1, C18.1, C19.1, C20.1, ENTREE.2, R18.1, U3.13 (VS)
VDD_3.3: C24.1, CONNECTEUR1.03, IC2.1 (VDD_1), IC2.5 (VDDA), IC2.17 (VDD_2), IC3.3 (VOUT)
VDD_12: C23.1, IC3.1 (VIN), IC3.2 (ON/OFF), R14.2, R19.1
V_OUT: C7.1, SORTIE.1

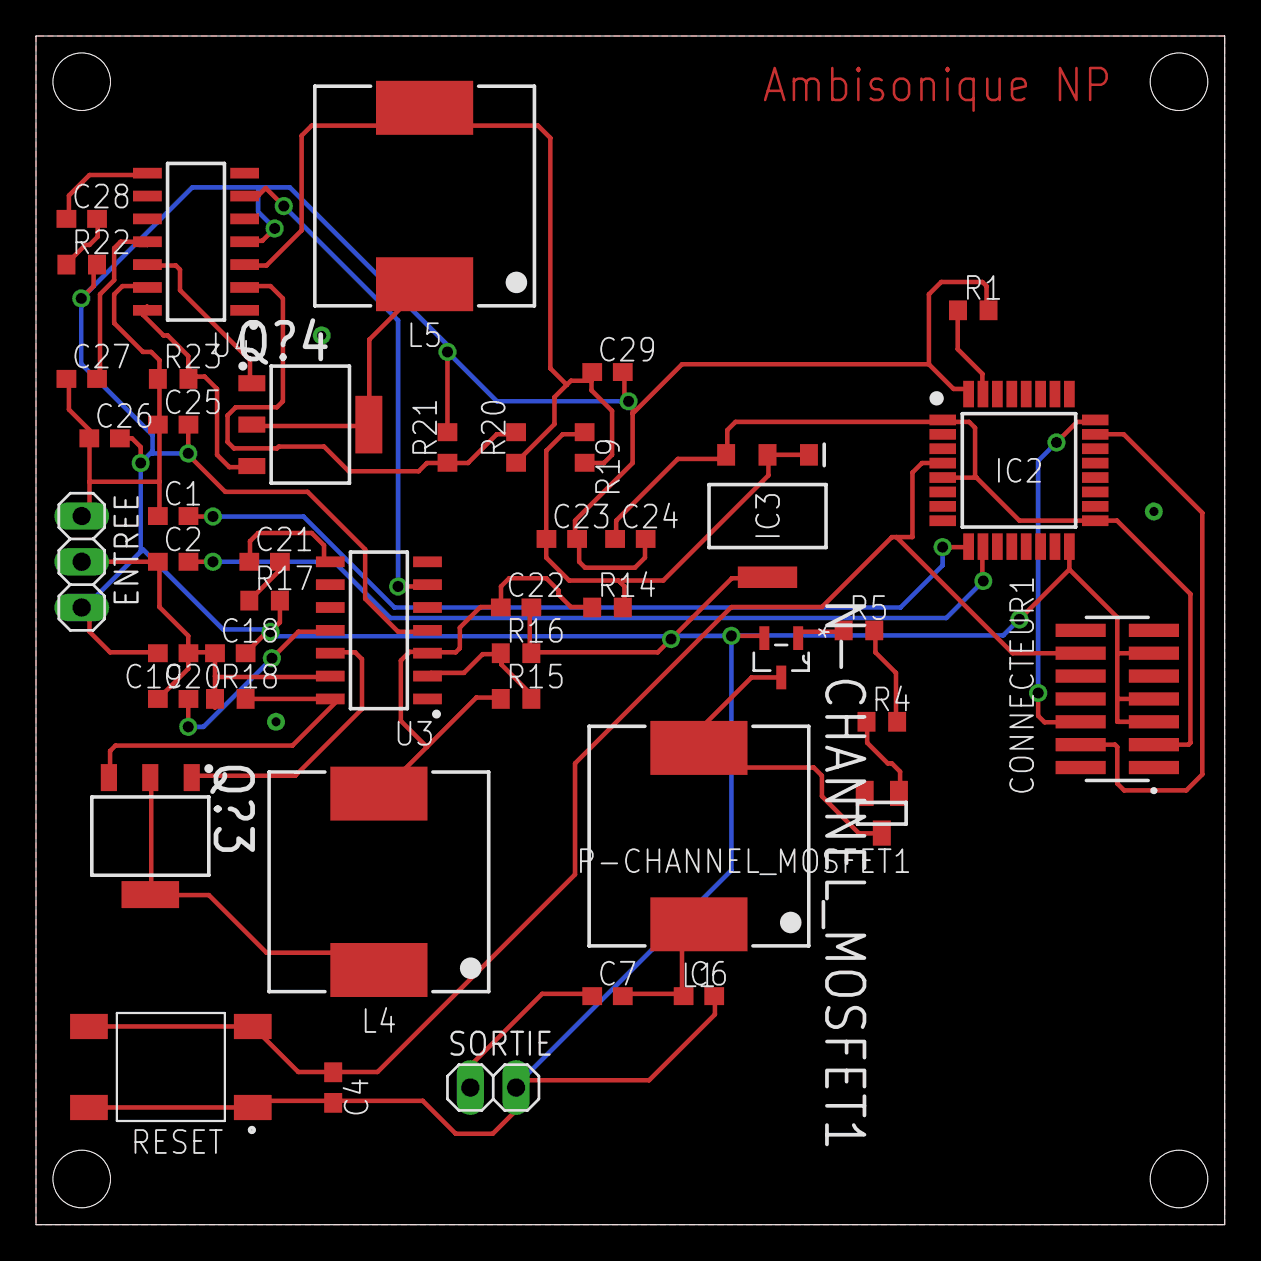
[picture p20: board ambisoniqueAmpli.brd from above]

Board: 2 copper layers, 66.0 x 66.0 mm, 45 parts (0 on the bottom side), 34 nets.

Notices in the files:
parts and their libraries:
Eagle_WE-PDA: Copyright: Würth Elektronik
